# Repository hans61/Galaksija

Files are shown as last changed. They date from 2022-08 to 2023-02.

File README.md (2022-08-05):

# Galaksija Plus

I became aware of the "Galaksija" in this forum:

https://forum.classic-computing.de/forum/index.php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

I find the Yugoslavian computer from 1983 based on a Z80 very interesting. Especially the idea to give it a SD card afterwards. Especially since it does not use a microcontroller, but implements the SPI interface with a 74LS299.

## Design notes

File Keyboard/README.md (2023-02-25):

# Galaksija keyboard matrix

My attempt to design a PCB for a keyboard of a Galaksija Plus.
Currently it is still untested!

For the first attempt I decided to use 12mm x 12mm styli.
Similar to the buttons here:

https://www.mouser.de/ProductDetail/CUI-Devices/TS13-1212-73-BK-100-D?qs=t7xnP681wgVrw7zKuc8u2g%3D%3D

with keycaps similar to these:

https://www.mouser.de/ProductDetail/Mountain-Switch/101-0110-EV?qs=eB3zOl243QFujTA3cWnhpg%3D%3D

My push buttons are from Aliexpress, something like this:

50PCS b3f-4055 12X1 2x 7,3mm 4PIN dip TACT push button schalter Micro key power tactile switches 12x1 2x 7,3 12*12*7,3 MM Licht touc
https://de.aliexpress.com/item/32853348805.html

https://de.aliexpress.com/item/32852734000.html

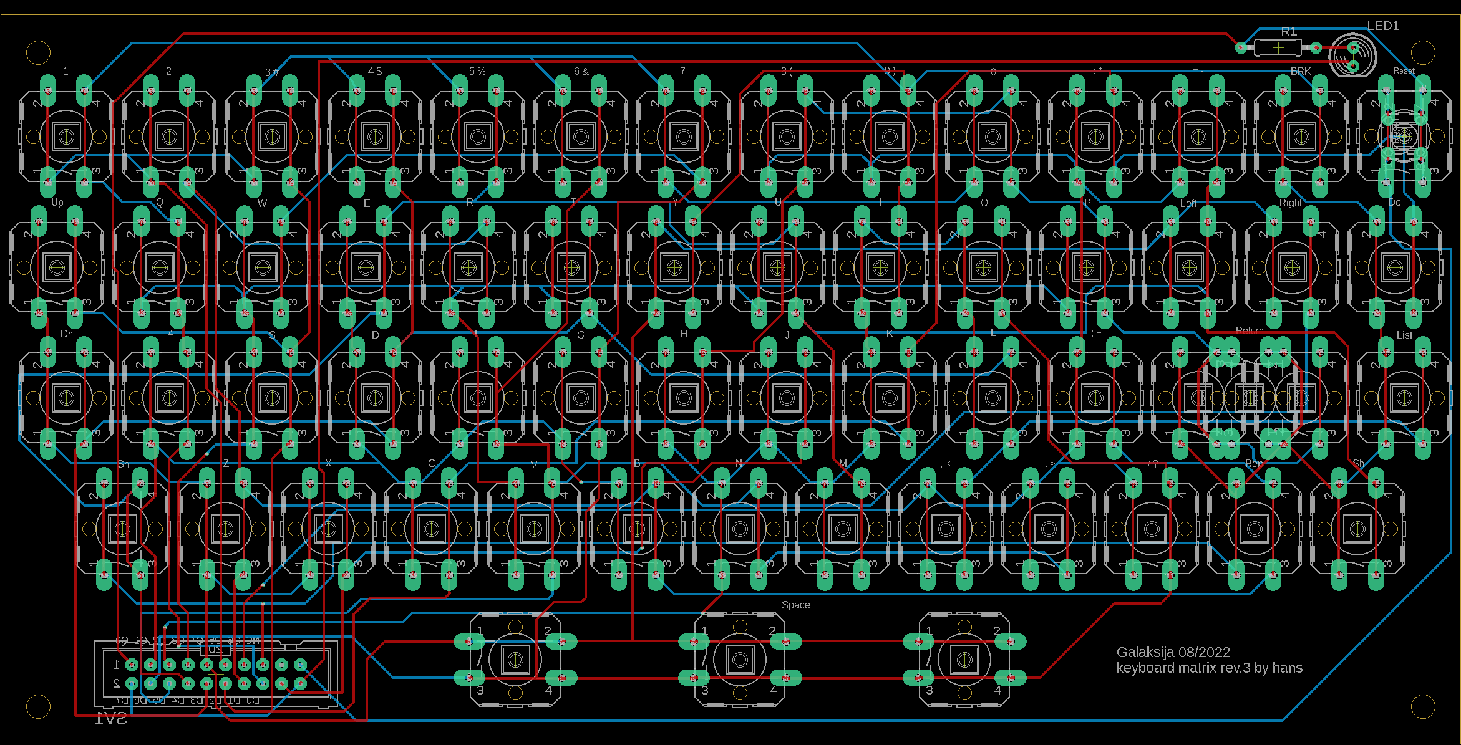
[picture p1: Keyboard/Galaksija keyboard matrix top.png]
keyboard pcb


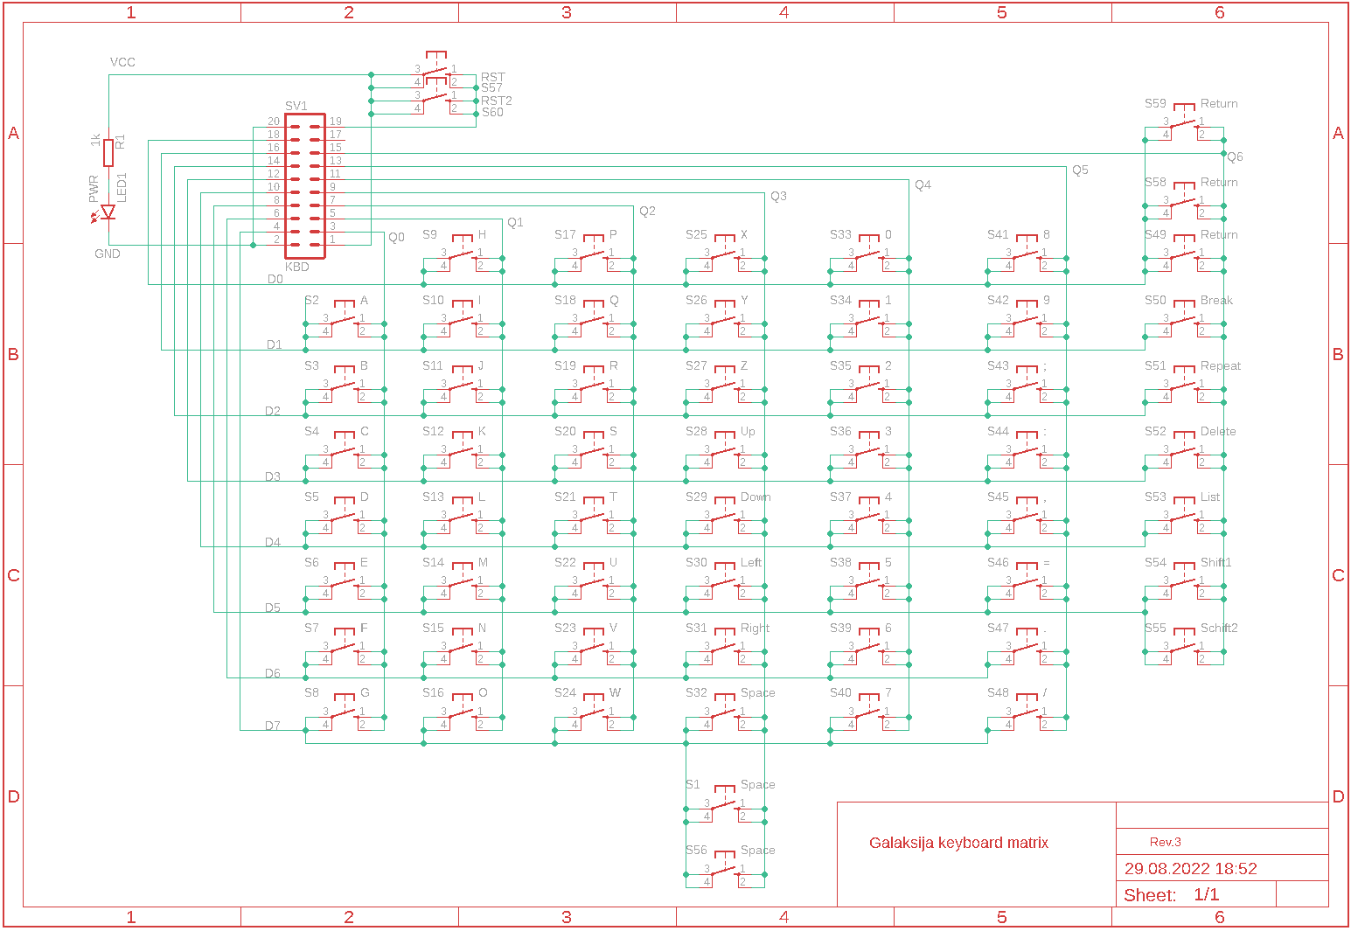
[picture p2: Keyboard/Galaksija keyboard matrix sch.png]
keyboard schematic


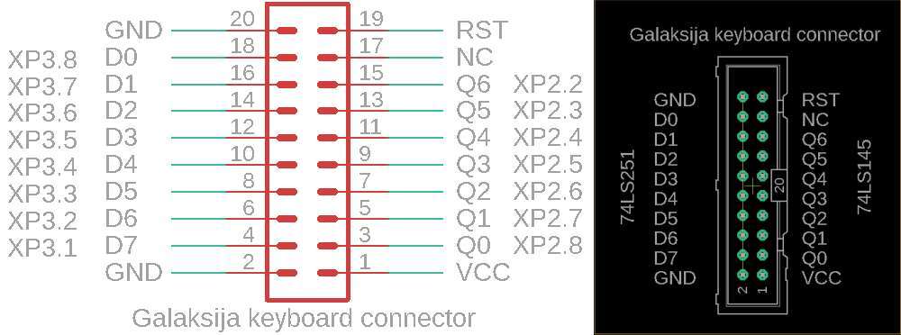
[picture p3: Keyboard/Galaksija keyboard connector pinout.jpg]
keyboard connector pinout


## Pictures of my build

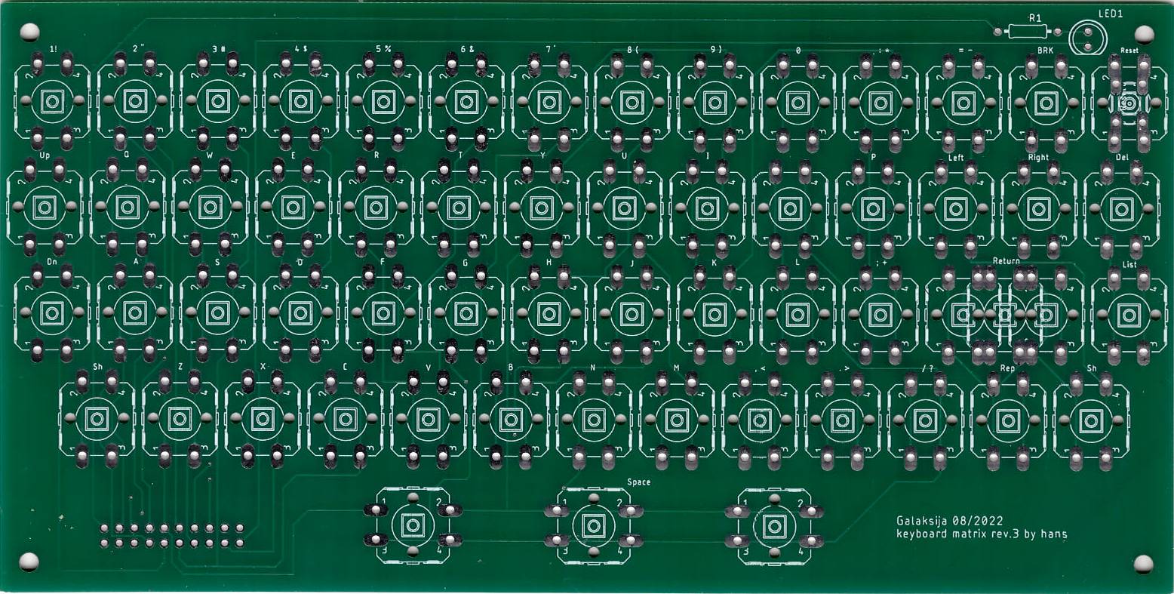
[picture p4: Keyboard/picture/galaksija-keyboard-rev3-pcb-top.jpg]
PCB


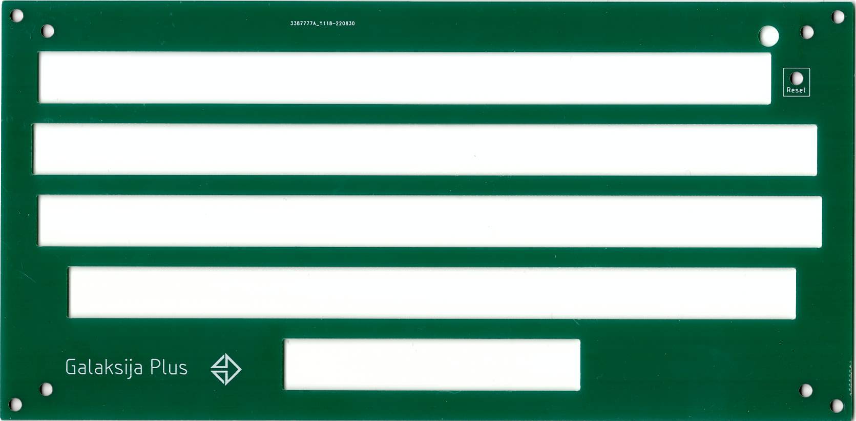
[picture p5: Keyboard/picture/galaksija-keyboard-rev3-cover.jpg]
Cover


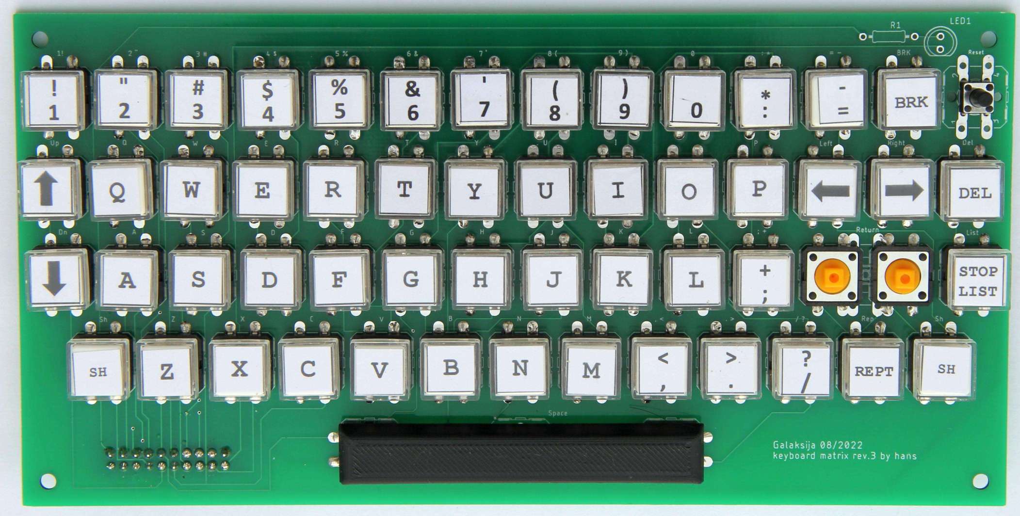
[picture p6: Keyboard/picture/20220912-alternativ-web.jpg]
PCB assembled


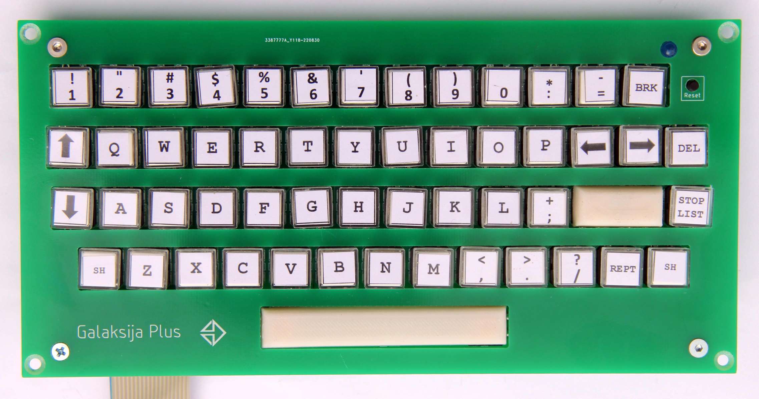
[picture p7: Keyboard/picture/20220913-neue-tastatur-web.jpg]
My Keyboard


## Adapter for Galaksija

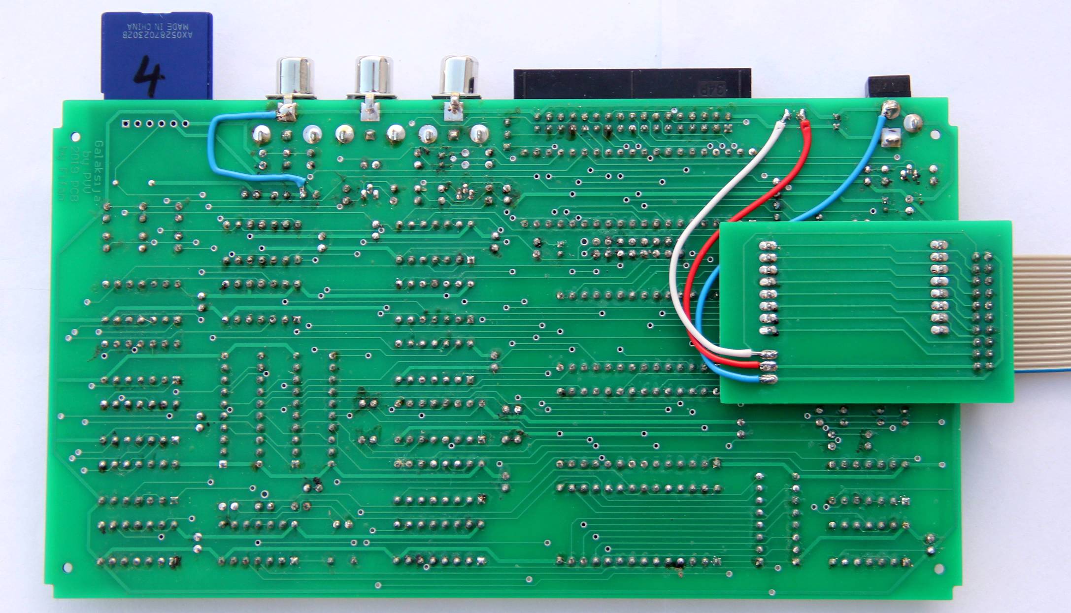
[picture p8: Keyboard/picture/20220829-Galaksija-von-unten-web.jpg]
bottom view


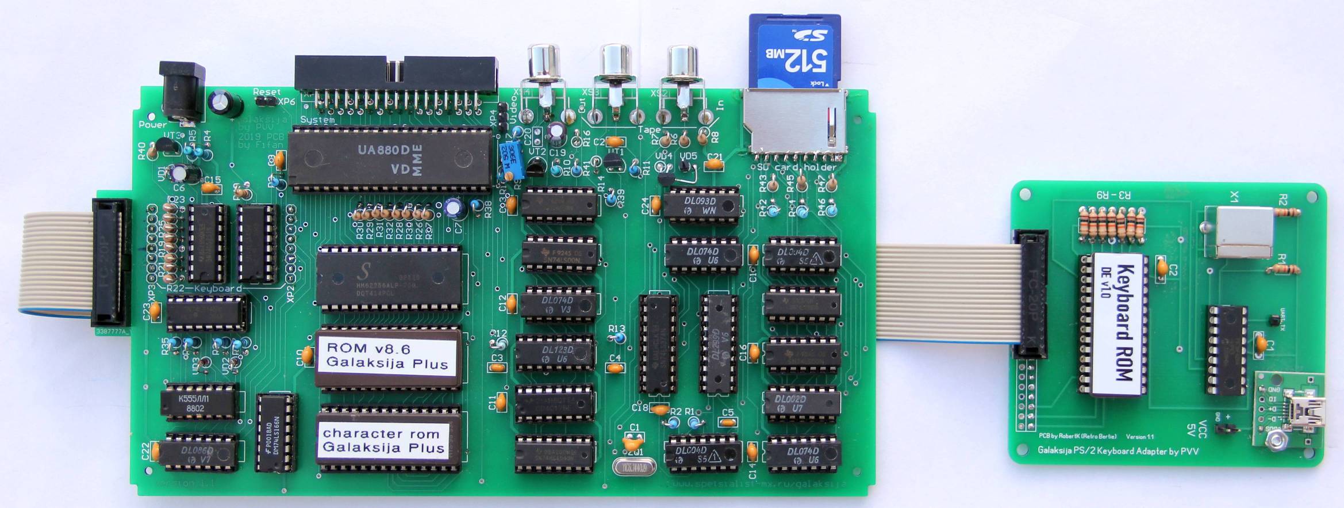
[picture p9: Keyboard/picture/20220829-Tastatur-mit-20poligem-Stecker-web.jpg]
Galaksija


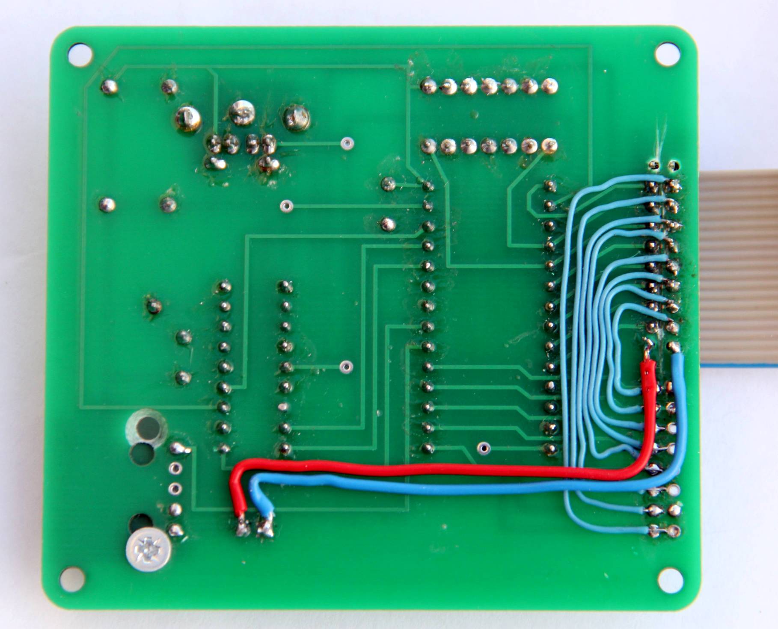
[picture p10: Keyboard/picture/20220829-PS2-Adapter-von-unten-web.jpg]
Modified PS2 adapter


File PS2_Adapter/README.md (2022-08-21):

# Galaksija keyboard rom

Ich habe mir den PS2 Tastaturadapter angesehen. Die Dekodierungssoftware im 16F628A wird praktisch nicht genutzt. Es scheint die Software aus einem anderen Projekt zu sein. Sie wird mit einem sehr einfachen Hack für das Galaksija genutzt.

Dabei werden lediglich die unteren 7 Bit des Letzen Scann Code-Bytes einer Taste an ROM Adresse A7..A13 gelegt. A0..A6 sind die Ausgänge des Galaksija 74LS145. Die Daten D0..7 bilden die Eingänge des 74LS251 auf dem Galaksija. A14 am ROM ist dann noch mit der Shift-Taste der Tastatur "verbunden". (1=Shift gedrückt, 0=nicht gedrückt)

Das bedeutet, die Scann Codes können mit gewissen Einschränkungen über den ROM in beliebige Tastatureingaben des Galaksija umgewandelt werden. Da immer der Scann Code der letzten gedrückten Taste am ROM anliegt kann die Mehrfachbetätigung von Tasten nicht ausgewertet werden.

Ich habe mir für die Erstellung des ROM ein Excel File gemacht und einen ROM für das Tastaturlayout DE gemacht. Das EN Layout werde ich bei Gelegenheit überarbeiten.
Der Zeichensatz des Galaksija besitzt kein einfaches Hochkomma, obwohl auf der Original Galaksija Tastatur vorhanden.

## Zeichensatz Galaksija

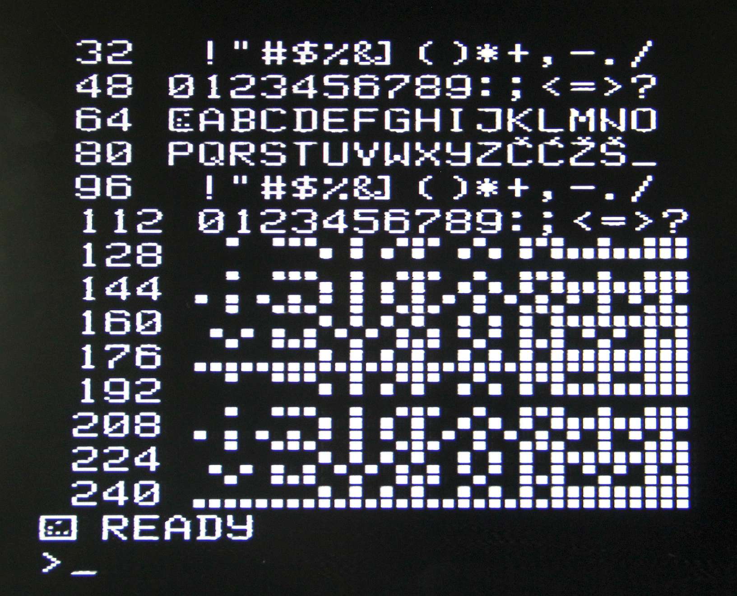
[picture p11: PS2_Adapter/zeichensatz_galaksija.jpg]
galaksija zeichensatz


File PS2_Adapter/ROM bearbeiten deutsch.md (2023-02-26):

# Aufbau des ROM
Der ROM ist nur eine große Nachschlagtabelle mit 32768 Werten. Dabei kommt der untere Teil der Adresse A0..6 direkt vom Galaksija (Spalten abfrage). Da der Galaksija jede Spalte einzeln testet (nie mehrere gleichzeitig), sind von den jeweils 128 möglichen Adressen nur 7 relevant.
Die Bits A7..14 kommen vom PIC, A15 ist nicht benutzt und immer 0 (GND).
A14 ist dabei die Shift-Taste und A7..13 ist des 7 Bit Scancode von der PS2 Tastatur. Der PIC berücksichtigt immer nur das letzte Byte des Scancode der gerade gedrückten Taste. Dies ist insbesondere bei Tasten zu berücksichtigen die mehrere Byte Scancode besitzen (z.B. im Num-Block)

Für die Erstellung es ROM habe ich mir eine Excel Tabelle gemacht. Dabei sind eigentlich nur die folgenden Spalten interessant (relevant).
### Tabelle ROM (DE/EN)
Excel Spalten
- C  ROM Adresse (nur zur Kontrolle oder zum Suchen im ROM)
- H  Scancode (kommt von der Tastatur und wird vom PIC ermittelt und ausgegeben)
- J  mit oder ohne Shift (von der PS2 Tastatur)
- L  vom Galaksija (Spalten C0..6 vom 74LS251)
- O  ROM Inhalt (dies ist die **EINZIGE** Spalte die geändert werden darf/muss (die Adressen sind vorgegeben)
### Tabelle Galaksija
Diese Tabelle, im Excel File, beinhaltet die einzelnen Zeilen/Spalten Zuordnung der Galaksija Tasten.

## Wie ändere ich eine Tasten im ROM
Dafür benötige ich den Scancode der Taste auf der PS2-Tastatur. Er ist im Excel-Blatt "Scancode" zu finden oder auch im Internet.  
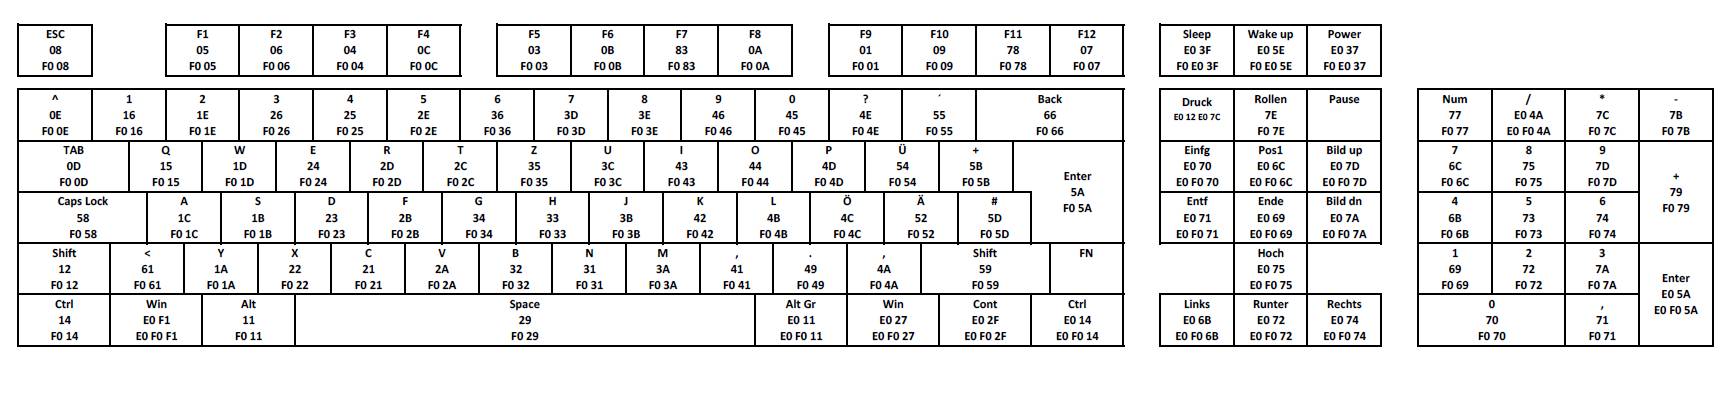
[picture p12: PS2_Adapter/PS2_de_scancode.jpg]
PS2 Tastatur Scancode
  
  
Als nächstes benötige ich die Spalte und Zeile für die Taste auf dem Galaksija (Excelblatt "GalaksijaTastatur").

Um die richtige ROM Adresse für diese Kombination zu finden benutze ich die Filter in der Excel-Tabelle.
Ich wähle nur den Scan Code in der Spalte H aus. Danach stelle ich in Spalte L den Wert für die Galaksija-Spalte ein.
Jetzt ist die Tabelle auf Zwei Einträge reduziert. Einer mit und einer ohne die gedrückte Shift-Taste. Im jeweils richtigen Eintrag wird jetzt der ROM-Inhalt (Excel Spalte O) auf den Wert für die Galaksija Spalte geändert.
Falls für das Zeichen auf dem Galaksija auch gleichzeitig die Shift-Taste gedrückt werden muss ist diese jetzt noch hinzuzufügen. Also der gleiche Scann Code (in Spalte H) und für die Galaksija Spalte 3F (Galaksija Shift) beim ROM-Inhalt ist hier DF in Excel-Spalte O einzutragen (Wieder die Gültigkeit beachten mit oder ohne Shift (oder beides)).

## Binary für ROM Erstellen
Für das Speichern der Binärdatei verwende ich das Programm "HxD Hex Editor"  
https://mh-nexus.de/en/hxd/  
Ich öffne diesen und gehe auf Neu (Strg+N). Jetzt Wechsel ich ins Excel. Im Excel-File (Arbeitsblatt DE|EN) alle Filter ausschalten, damit auch alle 32768 ROM Zeilen angezeigt werden.  
Markieren der ROM Daten in Spalte O kopieren und in HxD einfügen (Cursor in Zelle O4 mit "Shift+Strg+Pfeil nach Unten" alles bis zum letzten Datensatz markieren, dann Strg+C. Danach wechseln zu HxD und Strg+V).  
In HxD speichern als dateiname.bin und dann mit dem Brenner seiner Wahl den ROM brennen. Ich verwende einen TL866II mit der dazugehörigen Software.

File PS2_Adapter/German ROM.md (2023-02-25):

# Galaksija keyboard ROM deutsch

In der aktuellen Version habe ich ein paar kleine Fehler beseitigt.
Da es mit der aktuellen Firmware des PIC nicht möglich ist, das zwei gleichzeitig gedrückte Tasten erkannt werden, habe ich eine Änderung für das Keypad vorgenommen.

| Taste | Bewegung |
|---|---|
| Links (4) | links |
| Pos1 (7) | links und hoch |
| Hoch (8) | hoch |
| Bild hoch (9) | rechts und hoch |
| Rechts (6) | rechts |
| Bild runter (3) | rechts und runter |
| Runter (2) | runter |
| Ende (1) | links und runter  |

## Zuordnung von Galaksija Tasten
| Galaksija | PS2 Tastatur |
|---|---|
| LIST | ^ |
| REP | Rollen |
| BRK | ESC, F2 |
| DEL | F1 |

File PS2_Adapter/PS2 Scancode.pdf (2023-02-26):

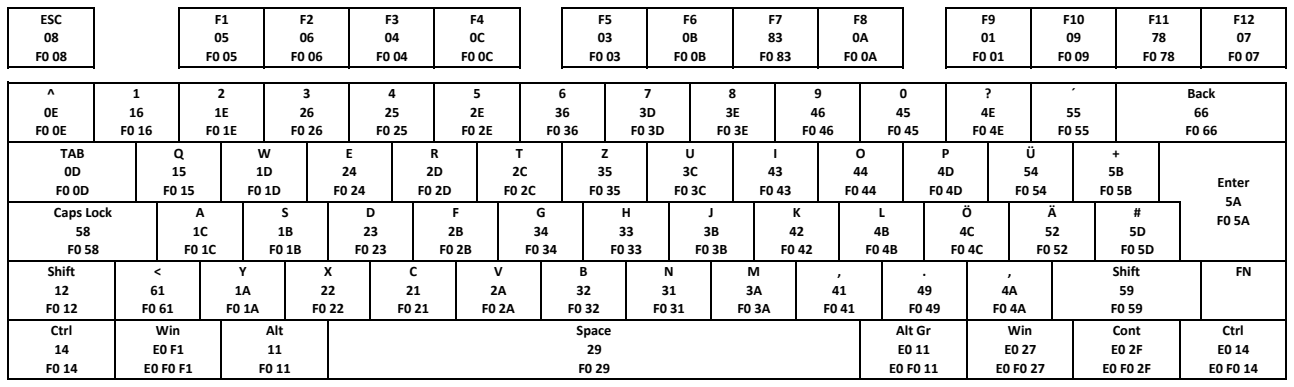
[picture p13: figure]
Shift 59 F0 59; Ctrl E0 14 E0 F0 14; Space 29 F0 29; Alt Gr E0 11 E0 F0 11; Win E0 27 E0 F0 27; Cont E0 2F E0 F0 2F; Enter 5A F0 5A; Back 66 F0 66; Caps Lock 58 F0 58; Shift 12 F0 12; Ctrl 14 F0 14; Win E0 F1 E0 F0 F1; Alt 11 F0 11; TAB 0D F0 0D; ESC 08 F0 08

3
7A
F0 7A
,
71
F0 71 | -7B F0 7B +79 F0 79 Enter E0 5A E0 F0 5A 070 F0 70

*
7C
F0 7C
7
6C
F0 6C

8
75
F0 75

9
7D
F0 7D
4
6B
F0 6B

5
73
F0 73

6
74
F0 74

Links
E0 6B
E0 F0 6B

Runter
E0 72
E0 F0 72

Rechts
E0 74
E0 F0 74

Hoch
E0 75
E0 F0 75

Num
77
F0 77

/
E0 4A
E0 F0 4A

1
69
F0 69

2
72
F0 72

Druck
E0 12 E0 7C

Rollen
7E
F0 7E

Pause

Einfg
E0 70
E0 F0 70

Pos1
E0 6C
E0 F0 6C

Bild up
E0 7D
E0 F0 7D
Entf
E0 71
E0 F0 71

Ende
E0 69
E0 F0 69

Wake up
E0 5E
F0 E0 5E

Power
E0 37
F0 E0 37

Bild dn
E0 7A
E0 F0 7A

Sleep
E0 3F
F0 E0 3F

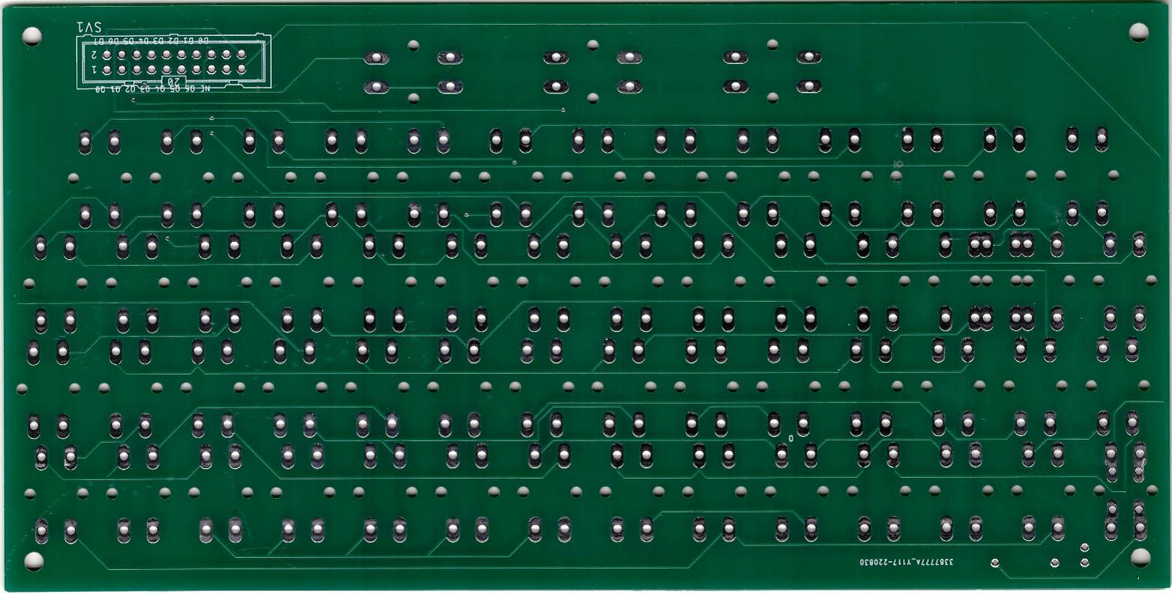
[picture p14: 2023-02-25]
Keyboard/picture/galaksija-keyboard-rev3-pcb-bottom.jpg

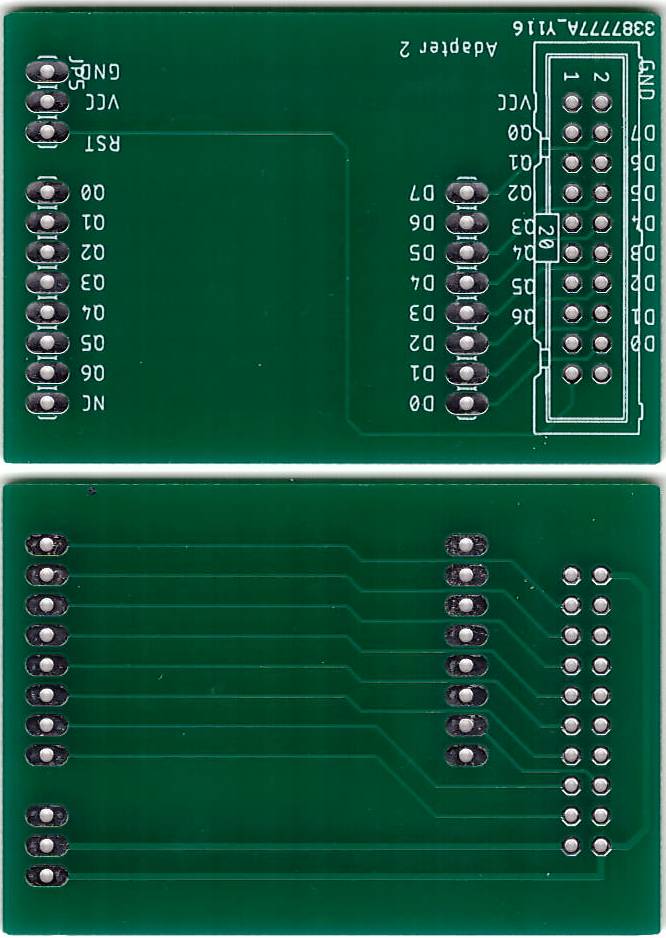
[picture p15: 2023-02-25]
Keyboard/picture/galaksija-keyboardadapter.jpg

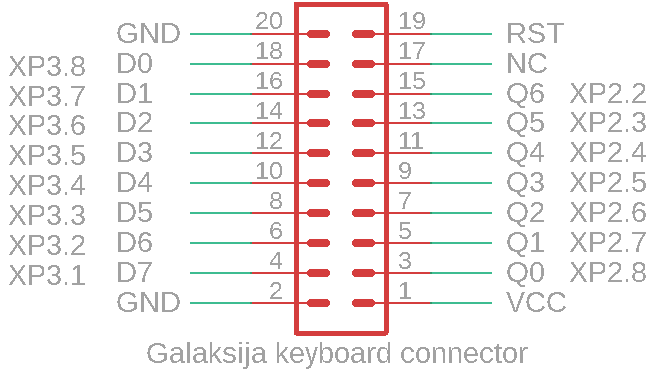
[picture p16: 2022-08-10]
Keyboard/eagle/rev2/Galaksija keyboard connector.sch.png

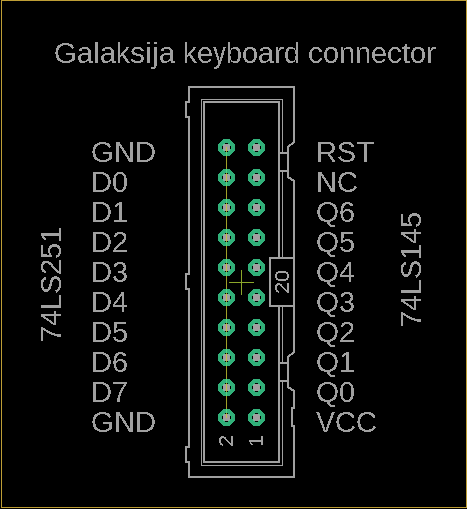
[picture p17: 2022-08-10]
Keyboard/eagle/rev2/Galaksija keyboard connector.brd.png

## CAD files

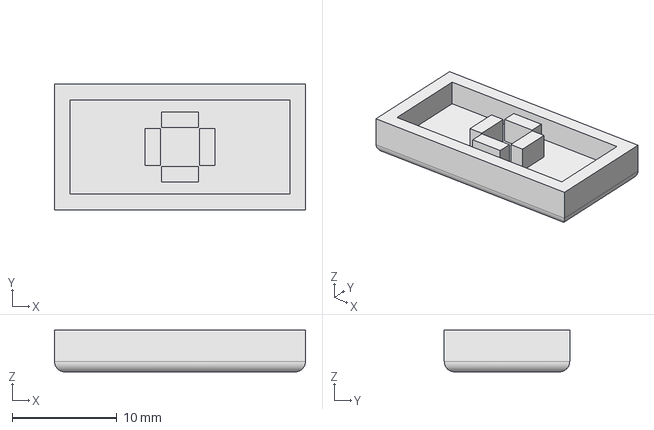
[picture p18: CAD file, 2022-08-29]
keys/keys-return.FCStd
24.0 x 12.0 x 4.00 mm

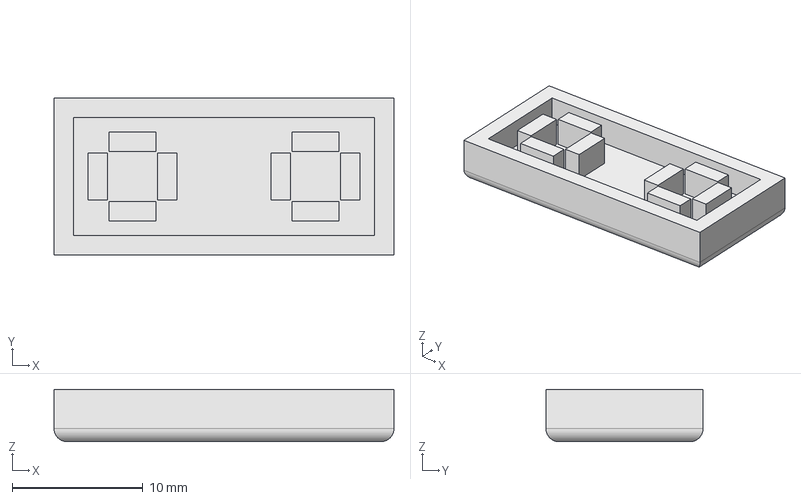
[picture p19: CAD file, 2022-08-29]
keys/keys-return2.FCStd
26.0 x 12.0 x 4.00 mm

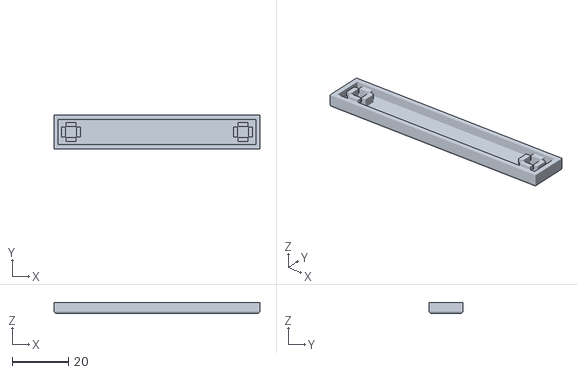
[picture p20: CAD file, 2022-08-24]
keys/keys-space.stl
73.0 x 12.0 x 4.00

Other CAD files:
keys/keys-return-rev2.stl
keys/keys-return2-rev3.stl
keys/key-space.FCStd

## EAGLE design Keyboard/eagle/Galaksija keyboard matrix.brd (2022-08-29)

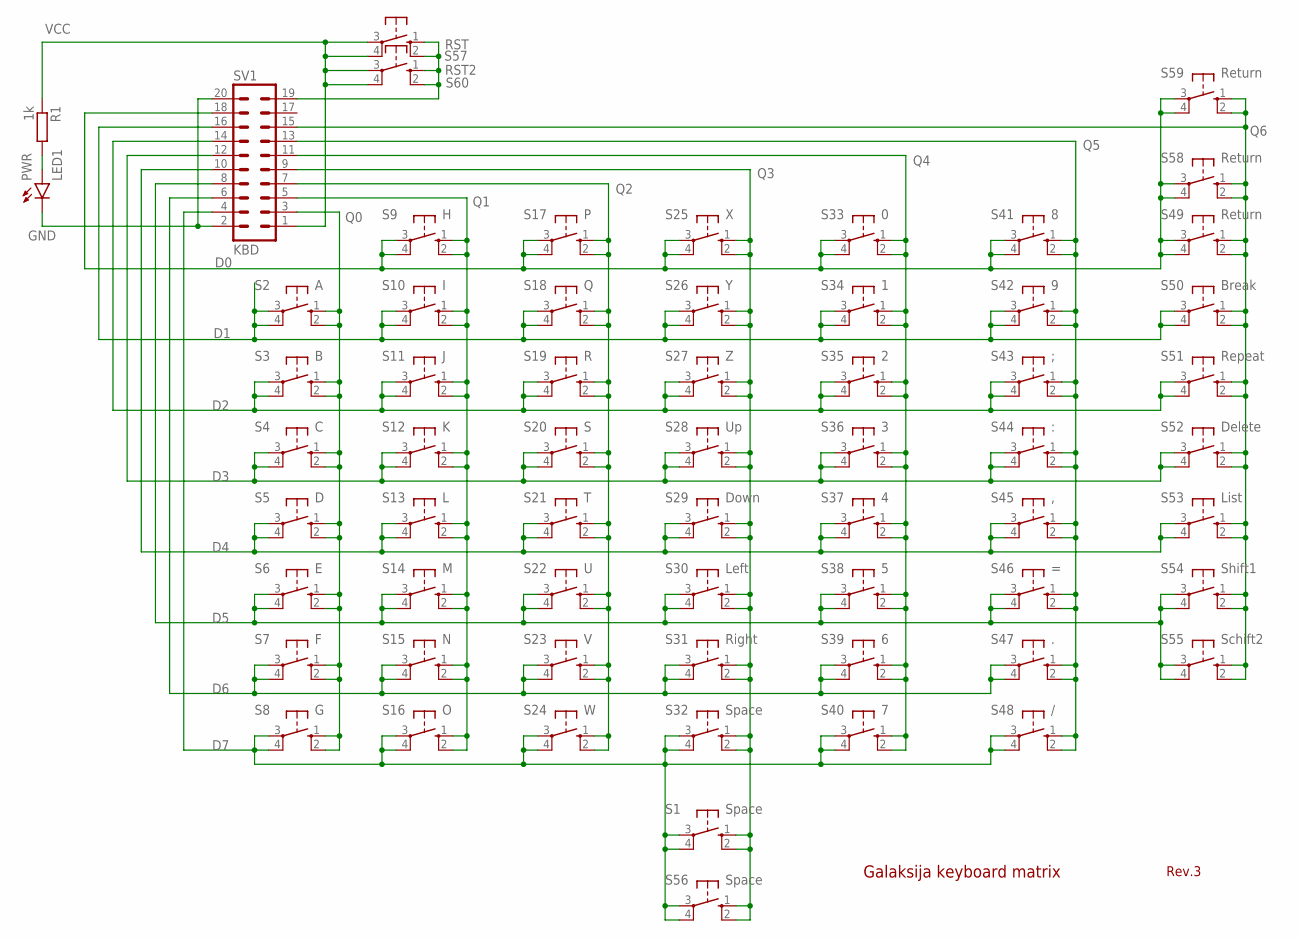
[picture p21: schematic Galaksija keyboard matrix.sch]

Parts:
LED1: PWR; LED5MM
R1: 1k; 0207/10
S1, S32, S56: Space; B3F-40XX
S2: A; B3F-40XX
S3: B; B3F-40XX
S4: C; B3F-40XX
S5: D; B3F-40XX
S6: E; B3F-40XX
S7: F; B3F-40XX
S8: G; B3F-40XX
S9: H; B3F-40XX
S10: I; B3F-40XX
S11: J; B3F-40XX
S12: K; B3F-40XX
S13: L; B3F-40XX
S14: M; B3F-40XX
S15: N; B3F-40XX
S16: O; B3F-40XX
S17: P; B3F-40XX
S18: Q; B3F-40XX
S19: R; B3F-40XX
S20: S; B3F-40XX
S21: T; B3F-40XX
S22: U; B3F-40XX
S23: V; B3F-40XX
S24: W; B3F-40XX
S25: X; B3F-40XX
S26: Y; B3F-40XX
S27: Z; B3F-40XX
S28: Up; B3F-40XX
S29: Down; B3F-40XX
S30: Left; B3F-40XX
S31: Right; B3F-40XX
S33: 0; B3F-40XX
S34: 1; B3F-40XX
S35: 2; B3F-40XX
S36: 3; B3F-40XX
S37: 4; B3F-40XX
S38: 5; B3F-40XX
S39: 6; B3F-40XX
S40: 7; B3F-40XX
S41: 8; B3F-40XX
S42: 9; B3F-40XX
S43: ;; B3F-40XX
S44: :; B3F-40XX
S45: ,; B3F-40XX
S46: =; B3F-40XX
S47: .; B3F-40XX
S48: /; B3F-40XX
S49, S58, S59: Return; B3F-40XX
S50: Break; B3F-40XX
S51: Repeat; B3F-40XX
S52: Delete; B3F-40XX
S53: List; B3F-40XX
S54: Shift1; B3F-40XX
S55: Schift2; B3F-40XX
S57: RST; B3F-40XX
S60: RST2; B3F-10XX
SV1: KBD; ML20

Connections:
D0: S9.3, S9.4 (P1), S17.3, S17.4 (P1), S25.3, S25.4 (P1), S33.3, S33.4 (P1), S41.3, S41.4 (P1), S49.3, S49.4 (P1), S58.3, S58.4 (P1), S59.3, S59.4 (P1), SV1.18
D1: S2.3, S2.4 (P1), S10.3, S10.4 (P1), S18.3, S18.4 (P1), S26.3, S26.4 (P1), S34.3, S34.4 (P1), S42.3, S42.4 (P1), S50.3, S50.4 (P1), SV1.16
D2: S3.3, S3.4 (P1), S11.3, S11.4 (P1), S19.3, S19.4 (P1), S27.3, S27.4 (P1), S35.3, S35.4 (P1), S43.3, S43.4 (P1), S51.3, S51.4 (P1), SV1.14
D3: S4.3, S4.4 (P1), S12.3, S12.4 (P1), S20.3, S20.4 (P1), S28.3, S28.4 (P1), S36.3, S36.4 (P1), S44.3, S44.4 (P1), S52.3, S52.4 (P1), SV1.12
D4: S5.3, S5.4 (P1), S13.3, S13.4 (P1), S21.3, S21.4 (P1), S29.3, S29.4 (P1), S37.3, S37.4 (P1), S45.3, S45.4 (P1), S53.3, S53.4 (P1), SV1.10
D5: S6.3, S6.4 (P1), S14.3, S14.4 (P1), S22.3, S22.4 (P1), S30.3, S30.4 (P1), S38.3, S38.4 (P1), S46.3, S46.4 (P1), S54.3, S54.4 (P1), S55.3, S55.4 (P1), SV1.8
D6: S7.3, S7.4 (P1), S15.3, S15.4 (P1), S23.3, S23.4 (P1), S31.3, S31.4 (P1), S39.3, S39.4 (P1), S47.3, S47.4 (P1), SV1.6
D7: S1.3, S1.4 (P1), S8.3, S8.4 (P1), S16.3, S16.4 (P1), S24.3, S24.4 (P1), S32.3, S32.4 (P1), S40.3, S40.4 (P1), S48.3, S48.4 (P1), S56.3, S56.4 (P1), SV1.4
GND: LED1.K (C), SV1.2, SV1.20
unnamed: LED1.A, R1.2
Q0: S2.1 (S), S2.2 (S1), S3.1 (S), S3.2 (S1), S4.1 (S), S4.2 (S1), S5.1 (S), S5.2 (S1), S6.1 (S), S6.2 (S1), S7.1 (S), S7.2 (S1), S8.1 (S), S8.2 (S1), SV1.3
Q1: S9.1 (S), S9.2 (S1), S10.1 (S), S10.2 (S1), S11.1 (S), S11.2 (S1), S12.1 (S), S12.2 (S1), S13.1 (S), S13.2 (S1), S14.1 (S), S14.2 (S1), S15.1 (S), S15.2 (S1), S16.1 (S), S16.2 (S1), SV1.5
Q2: S17.1 (S), S17.2 (S1), S18.1 (S), S18.2 (S1), S19.1 (S), S19.2 (S1), S20.1 (S), S20.2 (S1), S21.1 (S), S21.2 (S1), S22.1 (S), S22.2 (S1), S23.1 (S), S23.2 (S1), S24.1 (S), S24.2 (S1), SV1.7
Q3: S1.1 (S), S1.2 (S1), S25.1 (S), S25.2 (S1), S26.1 (S), S26.2 (S1), S27.1 (S), S27.2 (S1), S28.1 (S), S28.2 (S1), S29.1 (S), S29.2 (S1), S30.1 (S), S30.2 (S1), S31.1 (S), S31.2 (S1), S32.1 (S), S32.2 (S1), S56.1 (S), S56.2 (S1), SV1.9
Q4: S33.1 (S), S33.2 (S1), S34.1 (S), S34.2 (S1), S35.1 (S), S35.2 (S1), S36.1 (S), S36.2 (S1), S37.1 (S), S37.2 (S1), S38.1 (S), S38.2 (S1), S39.1 (S), S39.2 (S1), S40.1 (S), S40.2 (S1), SV1.11
Q5: S41.1 (S), S41.2 (S1), S42.1 (S), S42.2 (S1), S43.1 (S), S43.2 (S1), S44.1 (S), S44.2 (S1), S45.1 (S), S45.2 (S1), S46.1 (S), S46.2 (S1), S47.1 (S), S47.2 (S1), S48.1 (S), S48.2 (S1), SV1.13
Q6: S49.1 (S), S49.2 (S1), S50.1 (S), S50.2 (S1), S51.1 (S), S51.2 (S1), S52.1 (S), S52.2 (S1), S53.1 (S), S53.2 (S1), S54.1 (S), S54.2 (S1), S55.1 (S), S55.2 (S1), S58.1 (S), S58.2 (S1), S59.1 (S), S59.2 (S1), SV1.15
RST: S57.1 (S), S57.2 (S1), S60.1 (S), S60.2 (S1), SV1.19
VCC: R1.1, S57.3, S57.4 (P1), S60.3, S60.4 (P1), SV1.1

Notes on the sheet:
Galaksija keyboard matrix
Rev.3

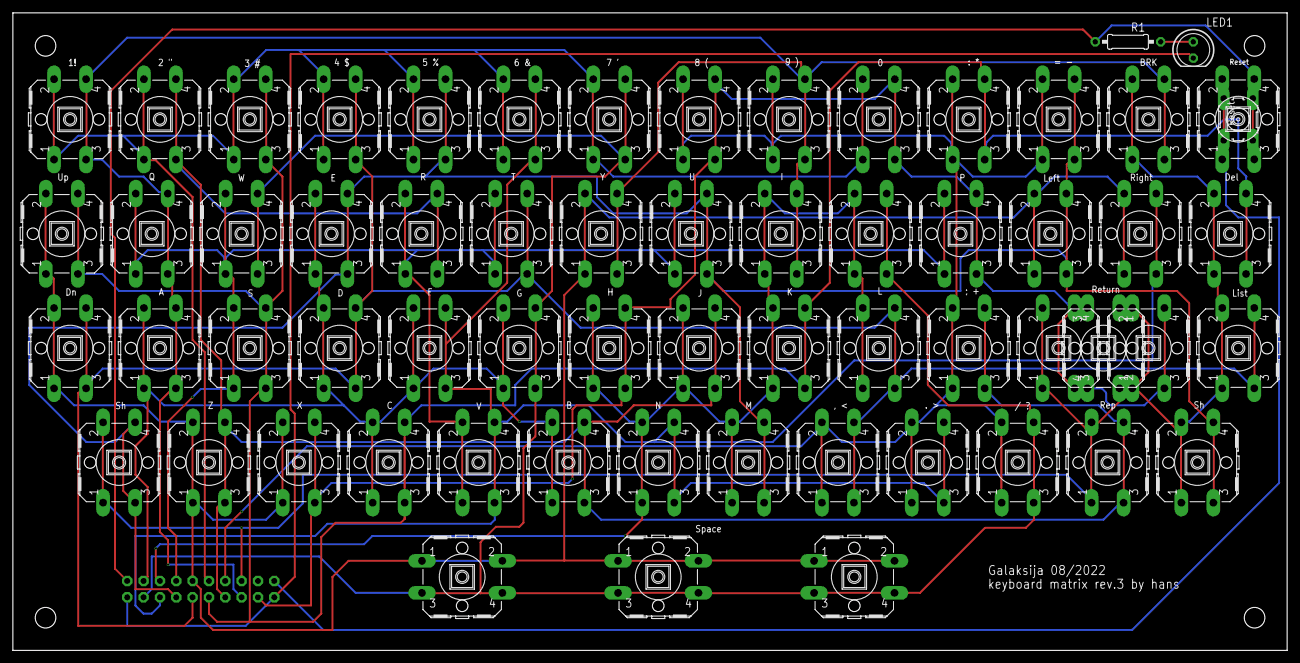
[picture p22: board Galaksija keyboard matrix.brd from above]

Board: 2 copper layers, 198.1 x 99.1 mm, 63 parts (1 on the bottom side), 19 nets.

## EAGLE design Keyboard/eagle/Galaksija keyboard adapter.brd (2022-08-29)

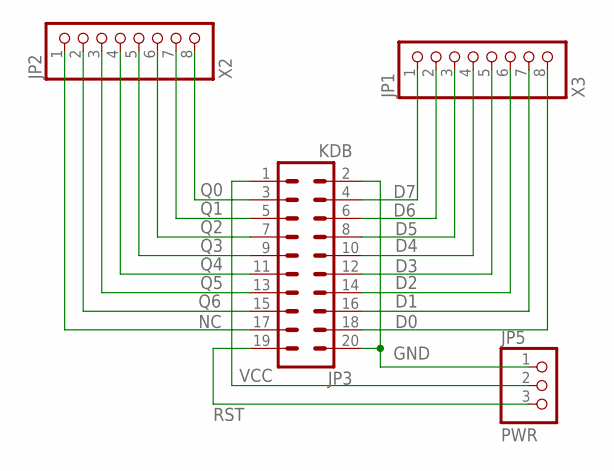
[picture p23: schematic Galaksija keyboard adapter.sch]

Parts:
JP1: X3; 1X08
JP2: X2; 1X08
JP3: KDB; ML20
JP5: PWR; 1X03

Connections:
D0: JP1.8, JP3.18
D1: JP1.7, JP3.16
D2: JP1.6, JP3.14
D3: JP1.5, JP3.12
D4: JP1.4, JP3.10
D5: JP1.3, JP3.8
D6: JP1.2, JP3.6
D7: JP1.1, JP3.4
GND: JP3.2, JP3.20, JP5.1
NC: JP2.1, JP3.17
Q0: JP2.8, JP3.3
Q1: JP2.7, JP3.5
Q2: JP2.6, JP3.7
Q3: JP2.5, JP3.9
Q4: JP2.4, JP3.11
Q5: JP2.3, JP3.13
Q6: JP2.2, JP3.15
RST: JP3.19, JP5.3
VCC: JP3.1, JP5.2

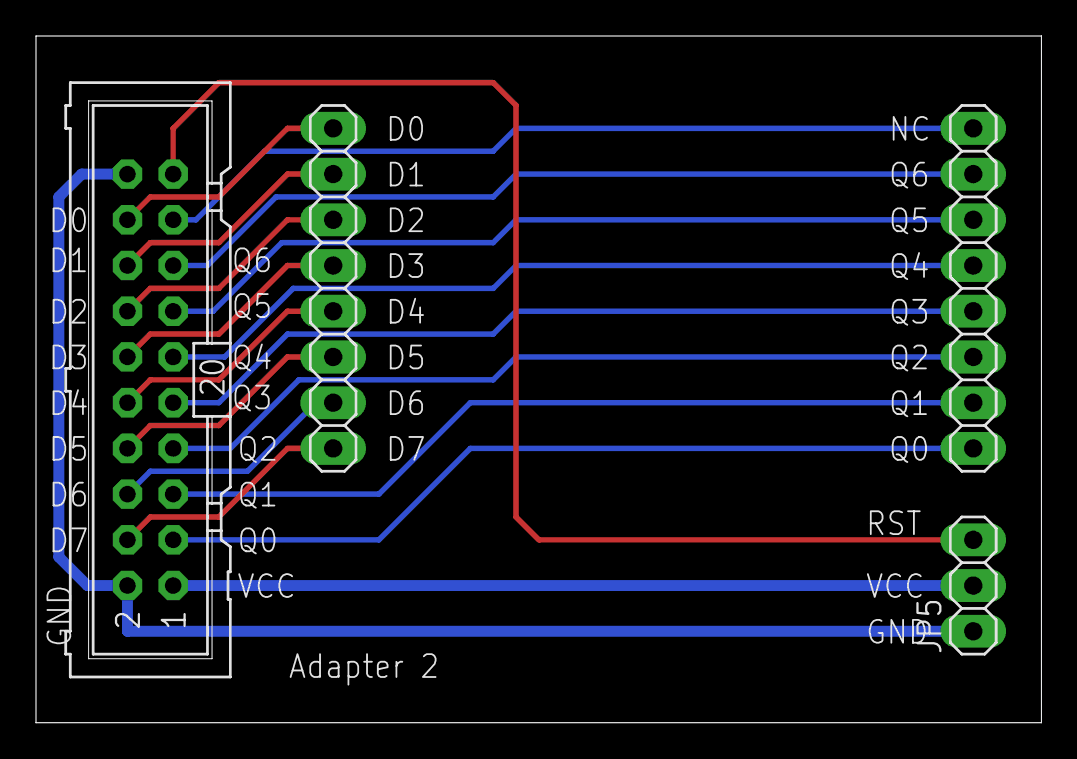
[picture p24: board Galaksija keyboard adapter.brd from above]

Board: 2 copper layers, 55.9 x 38.2 mm, 4 parts (0 on the bottom side), 19 nets.

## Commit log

2022-08-05 First version of the keyboard
    [Galaksija keyboard matrix.brd, Galaksija keyboard matrix.sch]
2022-08-08 New version Rev.2
    [Galaksija keyboard adapter.brd, Galaksija keyboard adapter.sch, Galaksija keyboard matrix.brd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]
2022-08-10 Keyboard connector pinout added
    [Galaksija keyboard connector.brd, Galaksija keyboard connector.sch, Galaksija keyboard matrix.sch]
2022-08-21 added keyboard rom de
2022-08-24 first version add keys
    [key-space.FCStd, keys-return.FCStd, keys-return.stl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]
2022-08-27 labeling for 10*10mm keys
    [keyboard label 10x10mm.xlsx]
2022-08-28 Rev3 narrower version with modified ENTER key
    [Galaksija keyboard matrix.brd, Galaksija keyboard matrix.sch]
2022-08-29 finished keyboard revision 3
    [Galaksija keyboard adapter.brd, Galaksija keyboard connector.brd, Galaksija keyboard connector.sch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]
2022-09-01 update keyboard lable
    [keyboard label 10x10mm.xlsx]
2023-02-25 cleaning keyboard files
    [Galaksija keyboard adapter.brd, Galaksija keyboard adapter.sch, Galaksija keyboard connector.brd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]
